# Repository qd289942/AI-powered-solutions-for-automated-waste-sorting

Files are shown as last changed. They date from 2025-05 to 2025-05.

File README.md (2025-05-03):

# 63184-fapra-ki-thema-1

Das Ziel des Projektes ist es, eine prototypische Fördereinrichtung zu erstellen,
welche vereinzelte Müllstücke transportiert. Die Müllstücke sollen
durch eine senkrecht über dem Förderband befestigte Kamera in Echtzeit
aufgenommen und durch einen KI-Basierten Bildverarbeitungsalgorithmus
ausgewertet werden. Die klassifizierten Müllstücke sollen anschließend durch
einen geeigneten Aktor vom Förderband entfernt und in die korrekte Müllgruppe
einsortiert werden.

Die Arbeit wurde im Rahmen des Moduls: “Fachpraktikum Softwareentwicklung
mit Methoden der Künstlichen Intelligenz” unter der Betreuung
von Dr. Otmane Azeroual erstellt. Die Aufgabenstellung mit dem Thema
„Automatisierte Mülltrennung und -entsorgung“ widmet sich, wie bereits
in vorherigen Kapiteln beschrieben, dem omnipräsenten Problem der Trennung
und Klassifizierung von kontinuierlich wachsenden Müllaufkommen.
Dieses Problem kann aus verschiedenen Blickwinkeln betrachtet und angegangen
werden, weswegen aus der Aufgabenstellung ein konkretes Vorgehen
und Projektziel abgeleitet wurde, welches in den nachfolgenden Abschnitten
beschrieben wird.

Das Projekt zielte auf die Automatisierung von Mülltrennung und -entsorgung ab und wurde erfolgreich als wissenschaftliche Arbeit veröffentlicht: "Intelligente Abfallwirtschaft: KI-gestützte Lösungen für automatisierte Mülltrennung und -entsorgung", Forschungsergebnisse zur Informatik, Band 75, Hamburg 2025 (ISBN 978-3-339-14368-6 Print / 978-3-339-14369-3 eBook). 

[Veröffentlichung](https://www.verlagdrkovac.de/978-3-339-14368-6.htm )

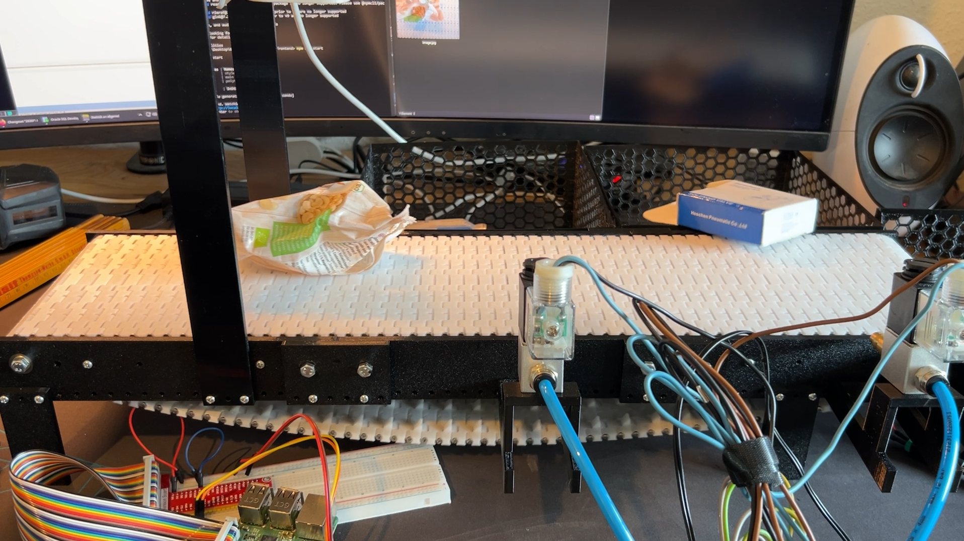
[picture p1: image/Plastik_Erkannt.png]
Förderband


## Starten der Anwendung
Zum starten der Anwendung folgen Sie bitte den Readme-Dokumenten des Frontends und des Backends

* [Backend](./backend/readme.md)
* [Frontend](./frontend/README.md)

## Standardbenutzer für Demozwecke
Zu Demozwecken stehen die beiden Nutzer admin und user zur Verfügung.
Die Passwörter entnehmen Sie bitte der env Datei des Backends.
[env](./backend/.env)
## Das vollständige Projekt-Demo
Das vollständige Projekt-Demo ist unter folgendem Link verfügbar:
[Video]https://drive.google.com/file/d/1swre4n_bvmbfQ7RDnxKk2m0LNGvAy1_f/view?usp=sharing

## Demo ohne Hardware
Ein detaillierte Demo-Video ohne Hardwareeinsatz wurde von unserem Teammitglied Herrn Teusch aufgenommen und ist unter folgendem Link einsehbar:
[Video](https://drive.google.com/file/d/1pbjZJ15CWwCAsQgvGXcbOX_87T2dLDAh/view)

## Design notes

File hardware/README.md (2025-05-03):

# Hardware
Für die Herstellung des Prototypen ...
benötigte Ausdrucke der Dateien:
 - 50x ChainFlat6Big.stl
 - 50x chainWithBottomTab6Big.stl
 - 2x FullFront6Big.stl
 - 2x Halterung Düse.stl
 - 2x Left.3mf
 - 2x Right.3mf
 - 2x middlerand6big.stl
 - 1x middlemiddle6big.stl
 - 4x Verbinder.stl
 - 2x wheel6big.stl

benötigte Gegenstände:
 - 4x QUARKZMAN 605ZZ 5x14x5mm Kugellager ([amazon.de](https://www.amazon.de/dp/B0BZP1FCC6?psc=1), [archive.org](https://web.archive.org/web/20240615102424/https://www.amazon.de/dp/B0BZP1FCC6?psc=1))
 - ca. 200x Linsenkopfschrauben DIN 7985 M2x3 bis M2x20 Kreuzschlitz ([ebay.de](https://www.ebay.de/itm/125243733851?var=426279012247), [archive.org](https://web.archive.org/web/20240615103334/https://www.ebay.de/itm/125243733851?var=426279012247))
 - 1x Druckluftkupplung Kupplungsstecker Außengewinde 1/4" ([amazon.de](https://www.amazon.de/dp/B003IJE1EG), [archive.org](https://web.archive.org/web/20240615102618/https://www.amazon.de/dp/B003IJE1EG))
 - 2x Elektrisches pneumatisches Magnetventil 2V025-08 12VDC PT1/4 2/2-Wege normalerweise geschlossen ([amazon.de](https://www.amazon.de/dp/B072ZZK9SD?psc=1), [archive.org](https://web.archive.org/web/20240615102828/https://www.amazon.de/dp/B072ZZK9SD?psc=1))
 - 1x Pneumatik Polyurethan PUN Schlauch 5 meter Außen 6mm x Innen 4mm ([amazon.de](https://www.amazon.de/dp/B071FM2H6R), [archive.org](https://web.archive.org/web/20240615103604/https://www.amazon.de/dp/B071FM2H6R))
 - 1x Kupplungsstecker mit Schlauchanschluss 6x4mm (mit Überwurfmutter) ([amazon.de](https://www.amazon.de/dp/B08KYQ4GB8), [archive.org](https://web.archive.org/web/20240615103808/https://www.amazon.de/dp/B08KYQ4GB8))
 - 1x Y-Stecker aus VooGenzek 20 Stück 6mm Air Push Schnellbefestigungen ([amazon.de](https://www.amazon.de/dp/B09NDNCQ89), [archive.org](https://web.archive.org/web/20240615104152/https://www.amazon.de/dp/B09NDNCQ89))
 - 1x 3 A 72W Verstellbarer Netzadapter, AC DC 3-24V Adapter Schaltnetzteil mit LED Spannungsanzeige ([amazon.de](https://www.amazon.de/dp/B09LCMMGJV), [archive.org](https://web.archive.org/web/20240615105202/https://www.amazon.de/dp/B09LCMMGJV))
 - 1x DC 12 V Getriebemotor, 25GA-370 25 Mm Durchmesser 12 V 30 U/min ([amazon.de](https://www.amazon.de/dp/B07HP6Z6CP), [archive.org](https://web.archive.org/web/20240615105715/https://www.amazon.de/dp/B07HP6Z6CP))

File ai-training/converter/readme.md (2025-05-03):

# Requirements

* Docker

# YOLOv8 to ONNX:

* Dockerfile: Dockerfile.yolov8_to_onnx
* Script: export_to_onnx.py

Build and Run:

```bash
docker build -t yolov8_to_onnx -f Dockerfile.yolov8_to_onnx .
docker run --rm -v $(pwd):/app yolov8_to_onnx #bash
```
```PowerShell
docker build -t yolov8_to_onnx -f Dockerfile.yolov8_to_onnx .
docker run --rm -v ${PWD}:/app yolov8_to_onnx #powershell
```

# YoloV8 to TensorFlow.js:
Legen Sie das exportierte YOLOv8 Model in den gleichen Ordner, wie
das Dockerfile.yolov8_to_tfjs.

Passen Sie im Dockerfile innerhalb des Bereiches ENTRYPOINT den Namen des Models an.
Dieser ist derzeit auf "detection.pt" eingestellt.

Achtung das erzeugte Image besitzt eine größe von ca. 13GB!

* Dockerfile: Dockerfile.yolov8_to_tfjs

Build and Run:
```bash
docker build -t yolov8_to_tfjs -f Dockerfile.yolov8_to_tfjs .
docker run --rm -v $(pwd):/app yolov8_to_tfjs #bash
```

```PowerShell
docker build -t yolov8_to_tfjs -f Dockerfile.yolov8_to_tfjs .
docker run --rm -v ${PWD}:/app yolov8_to_tfjs #PowerShell
```

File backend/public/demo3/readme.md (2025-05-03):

# Socket.IO Demo
Dies ist nur eine Demo, um die Arbeitsweise von Socket.IO zu veranschaulichen und eine Integration bestehnde Projekt zu demonstrieren.

Um die Demo zu testen muss das Projekt geklont werden, und die npm module installiert werden, siehe dazu readme für das Backend [klick](../../readme.md)

Anschließend muss der server gestartet werden `npm start`
Dann ruft man über einen Webbrowser die beiden folgenden links auf (der Port muss ggf. geändert werden, falls nicht der default Port verwendet wurde.)
* [https://localhost:3000/demo1](https://localhost:3000/demo1)
* [https://localhost:3000/demo3](https://localhost:3000/demo3)

Wenn man nun in Demo 1 ein Bild hochlädt und dort Müll erkannt wird, erhält Demo 3 ein Signal und Schaltet seinen Aktor an. Dieser wird dann automatisch nach 3 Sekunden wieder ausgeschaltet, um den Luftstoß zu signalisieren.
Derzeit ist noch zu definieren, wie die Das Objekt des Servers aussehen soll. Hier sollten wir uns auf einen Interface einigen. 
Anschließend stellt sich noch die Frage, ob für alle Aktoren Befehle empfangen möchte, oder ob das Backend für einen Aktor eine
eigene Route erstellen soll, auf die man sich dann verbindet. 

# Socket.IO Python Demo

Für die Python Version muss natürlich Pyhton installiert sein.
Anschließend muss noch das Socket.IO Modul installiert werden `pip install "python-socketio[client]"`.
Bevor nun der Python client gestartet wird sollte das Backend gestartet werden, dazu wie in der [Readme des backends verfahren](../../readme.md)
anschließend kann der test mittels `py.exe .\socketio-test.py` aus dem order backend\public\demo3 getartet werden.

Die Konsole sollte offen bleiben.
Öffnet man nun [https://localhost:3000/demo3](https://localhost:3000/demo3)

Weitere Referenzen unter: 
https://python-socketio.readthedocs.io/en/latest/client.html#installation

# Registrierung eines Aktores auf eine Socket.IO Route
Damit ein Aktor über eine erkannte Müllklasse informiert werden kann, muss sich dieser auf seine eigene Socket verbinden.
Jeder Aktor erhält somit seine eigene Socket.io Route, über die informiert wird. 
Die Route ist wie folgt aufgebaut: 

```trash_detected/${actuatorId}```

Ein Beispiel für den Aktor mit der ID 1 wäre

trash_detected/1

Ein Beispiel für den Aktor mit der ID 15 wäre
trash_detected/15

in form von Python Code könnte dies so aussehen: 
```python
sio.on('trash_detected/1', trigger_actuator)
```

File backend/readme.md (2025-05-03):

# Installation des Backends

> Voraussetzungen für die Installation:
> * [Node.js](https://nodejs.org/en/download)
> * [Docker](https://www.docker.com/products/docker-desktop/)

1. Klonen Sie das Repository mittels git clone
```bash
git clone https://code.dbis-pro1.fernuni-hagen.de/fpniteus/63184-fapra-ki-thema-1.git
```

2. Navigieren Sie in das Verzeichnis backend 
```bash
cd backend
```

3. Installieren Sie die Node-Modules mittels
```bash
npm install
```

4. Kopieren einer benötigten dll in das ein Tensorflow unterverzeichnis. Weitere Informationen können diesbezüglich [Fehler-nach-Installation](#Fehler-nach-Installation)
```bash
cp .\node_modules\@tensorflow\tfjs-node\deps\lib\tensorflow.dll .\node_modules\@tensorflow\tfjs-node\lib\napi-v8\
cp .\node_modules\@tensorflow\tfjs-node\deps\lib\tensorflow.dll .\node_modules\@tensorflow\tfjs-node-gpu\lib\napi-v8\
```

Die folgenden Schritte sind Optional und werden nur benötigt, wenn die KIs auf der GPU Laufen sollen.

Voraussetzungen: 
* NVIDIA Grafikkarte
The following NVIDIA® software are only required for GPU support.

* Windows Native Requires Microsoft Visual C++ Redistributable for Visual Studio 2015, 2017 and 2019
NVIDIA® GPU drivers
* >= 525.60.13 for Linux
* >= 528.33 for WSL on Windows (Falls keine native Ausführung auf Windows gewünscht ist.)
* CUDA® Toolkit 12.3.
* cuDNN SDK 8.9.7.
* (Optional) TensorRT to improve latency and throughput for inference.

[Eine Installationsanleitung für CUDA kann hier entnommen werden](https://www.tensorflow.org/install/pip#windows-native_1)

# Starten des Backends
Nach der [Installation](#Installation-des-Backends) sollte zuerst die Datenbank gestartet werden. Navigieren Sie hierzu in den Unterordner backend und führen `docker-compose up` aus. Es sollte nun ein docker-container mit der Datenbank gestartet werden. Anschlißeend kann mittels `npm start` das Node.js backend gestartet werden.

# Ausführen von Testfällen
Die Testfälle können mittels des Befehls `npm test` im Untterordner backend ausgeführt werden.

# Fehler nach Installation
Dieser Fehler trat nur unter Windows (x86_64) auf. Die Installation unter macOS M1 ARM verlief fehlerfrei.

```
node:internal/modules/cjs/loader:1189
return process.dlopen(module, path.toNamespacedPath(filename));
```

Nach der Installation wurde ein Fehler angezeigt, dass ein Modul nicht geladen werden konnte.

hierzu muss eine dll in den Entsprechenden Ordner kopiert werden.

```bash
cp .\node_modules\@tensorflow\tfjs-node\deps\lib\tensorflow.dll .\node_modules\@tensorflow\tfjs-node\lib\napi-v8\
```

[Quelle](https://github.com/tensorflow/tfjs/issues/8176)

# Docker einrichten & DB aufsetzen

`docker compose up -d`

DB Index über Kibana http://127.0.0.1:5601/app/dev_tools#/console anlegen:

```http request
PUT detected_garbage
{
  "mappings": {
    "properties": {
      "bounding_box": {
        "properties": {
          "height": {
            "type": "float"
          },
          "width": {
            "type": "float"
          },
          "x": {
            "type": "float"
          },
          "y": {
            "type": "float"
          }
        }
      },
      "detection_certainty": {
        "type": "float"
      },
      "detection_class": {
        "type": "keyword"
      },
      "detection_timestamp": {
        "type": "date"
      },
      "img_path": {
        "type": "keyword"
      },
      "tracking_id": {
        "type": "keyword"
      },
      "x_detection_threshold" : {
        "type": "float"
      },
      "ai_id" : {
        "type": "long"
      },
      "operation_section_id" : {
        "type": "long"
      }
    }
  }
}
```

Ist der Index bereits vorhanden, kann er mithilfe des folgendes Requests gelöscht werden,
dabei gehen alle bereits gespeicherten Daten verloren:

```http request
DELETE detected_garbage
```

Möchte man nur die gespeicherten Daten entfernen ohne den Index selbst zu entfernen kann folgender Request genutzt werden:

```
POST detected_garbage/_delete_by_query
{
    "query": {
        "match_all": {}
    }
}
```

## Rebuild der Container durchführen
Falls Änderungen an den Cotnainers durchgeführt werden kann es notwendig sein einen rebuild durchzuführen.
Dies ist beispielsweise der Fall, wenn das KI-Modell ausgetauscht wurde, jedoch noch den gleichen Namen besitzt.
Führen Sie in diesem Fall folgenden Befehl aus: 

`npm run rebuild-container`

# Eindung weiterer KI-Modelle

Zur Einbinden weiterer KI-Modelle müssen in das Tensorflow.JS-Format konvertiert werden.
Hierfür kann der Konverter unter ai-training/converter genutzt werden. Lesen Sie die dort vonrhandene [readme.md](../ai-training/converter/readme.md)
für die Konvertierung.

Anschließend erhalten Sie ein verzeichnis mit dem Namen des exportierten Modells. Dieses sollte einer gewissen Anzahl an shard-Dateinen bestehen, eine metadata.yml sowie eine model.json enthalten.

Kopieren Sie dieses Verzeichnis nach `backend/src/models/`
Anschließend kann eine neue Instanz der Klasse YoloV8 erzeugt werden.
Übergeben Sie dem Konstruktor den Namen des Ordners (modelName).
Zuletzt muss das erzeugte Objekt, dem ObjectDetectionRouter mit den anderen KIs übergeben werden.

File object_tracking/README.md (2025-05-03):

# Prototyp Objektverfolgung (object-tracking)

In diesem Teilprojekt sollen Lösungsansätze für das Problem object-tracking (Wiederkennung von Objekten über mehrere Frames hinweg) evaluiert werden.

Da dieses Teilprojekt einen reinen Prototyp-Charakter hat wurden die Skripte unter zuhilfenahme von ChatGPT 4o von OpenAI in Grundzügen erstellt und händisch
in seiner Funktionsweise komplettiert.

Beim Ordner 

## Vorbereitung der Umgebung

Das Projekt muss in `PyCharm Professional` geöffnet werden, dieses sollte nach dem öffnen automatisch, eine virtuelle Umgebung `venv` erstellen,

Falls dies nicht der Fall ist muss diese manuell erstellt werden, Python `3.12.3` ist Voraussetzung.

Für die Evaluation wurde yolov5 (Ein vortrainiertes Model mit niedriger Inferenzzeit) verwendet, dies muss mittels folgendem Befehl ins Hauptverzeichnis gecloned werden:

`git clone https://github.com/ultralytics/yolov5`

Dann müssen Folgende Abhängigkeiten müssen mittels folgender Befehle unter Verwendung von `pip` installiert werden

```
pip install -r yolov5/requirements.txt
pip install opencv-python opencv-python-headless ultralytics deep_sort_realtime
pip install numpy opencv-python
pip install torch torchvision
```

Nach diesem Schritt sind alle Abhängigkeiten installiert.

## Vorbereitung und Ausführung der Evaluation mittels Projekt-Skripten

Um das Projekt zu benutzen müssen zunächst 3 Videos unter `./video` abgelegt werden.

Es gibt folgende Python-Skripte mit ihren jeweiligen Teilaufgaben welche in der folgenden Reihenfolge ausgeführt werden müssen:

* `split_to_frames.py`
  * zerschneidet die in `video` abgelegten Videos in einzelne Frames, welche unter `./frames` abgelegt werden
* `detect_objects.py`
  * Nutzt ein KI-Model um object-detection auf die in `./frames` gespeicherten Bilder auszuführen und schreibt die Bilder inklusive Klassifizierung
und bounding-box in `./detection`. Hierbei handelt es sich lediglich um einen Schritt der bessere Nachvollziehbarkeit der Effektivität des object-trackings gewährleisten soll.
* `track_objects.py`
  * Nutzt ein KI-Model (es muss dasselbe wie im vorherigen Schritt sein) um object-detection und anschließend object-tracking durchzuführen.
  * Das Ergebnis (Bilder mit BBoxes und IDs) wird unter `./tracking` abgelegt.
* `create_videos.py`
  * Nutzt die unter `./tracking` abgelegten Bilder und erstellt daraus Videos zur besseren Veranschaulichung 

Am Ende stehen die im letzten Schritt erzeugten Videos unter `end_results` zur Verfügung.

In diesem Teilprojekt geht es aktuell um die qualitative Evaluation von object-tracking Ansätzen, daher werden aktuell keine Metriken zur Präzision
ermittelt.

## Quick-Demo

Unter dem Link https://drive.google.com/drive/folders/12NR1LaL0RtI5wm9HxKmUK7CR1UAvKl8M?usp=drive_link#
gibt es alle Dateien welche während einem Probelauf entstanden sind.

## Aktueller Stand

Zunächst wurde die Evaluation mittels einem nicht nachtrainierten `yolov5` durchgeführt.

Dabei zeigte sich, dass der bisherige Ansatz `DeepSort` qualitativ erfolgversprechend aussieht.

Der nächste Schritt besteht nun das object-tracking mittels eines angepassten models zu trainieren.

Die dafür nötigen Anpassungen sind zum jetzigen Zeitpunkt noch nicht final, aktuelle Versionen der modifizierten Skripte werden
unter `wip_aligned` abgelegt.

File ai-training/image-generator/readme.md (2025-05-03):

# Kurzbeschreibung

Der Imagegenerator erzeugt jede Sekunde einen Screenshot, von dem Bild, welches die Kamera gerade aufnimmt und speichert es im Format
640x640 px im Backend im unterordner ./images.

# Installation
1. Navigieren Sie in den Unterordner image-generator
2. führen Sie ein `npm i` aus, um die Node-Moduels zu installieren
3. Starten des Image-Generators mittels `npm start`
4. Der Image-Generator ist nun unter https://localhost:3001/ erreichbar

# Wechseln der Kamera
Der Image-Generator selbst besitzt keine eigene möglichkeit die Ausgewählte Kamera zu ädern. Hierfür muss auf die eingebauten funktionen des Browsers zurückgegriffen werden.

1. Google Chrome starten
2. https://localhost:3001 aufrufen
3. Richtige Kamera auswäheln
   1. Auf Kamera Symbol in der URL Leiste klicken

    

   2. Manage
   
   

   3. Auf das Kamera Dropdown klicken
   
   

   4. Richtige Kamera auswählen
   
   
   
   5. Seite neu laden

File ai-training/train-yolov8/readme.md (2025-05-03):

# Training von YOLOv8 Detektions/Klassifikations-Modell

In diesem Test wurde YOLOv8 Verwendet und es mit einem Dataset für Mülltrennung trainiert. Zuerst wird ein Klassifikationsmodell mit einem Datensatz von Kaggle trainiert und anschließend ein Detektionsmodell mit Bildern sowohl von Kaggle als auch von einem Förderband trainiert.

Hierbei handelt es sich um einen Versuch, eines Basismodells (yolov8s für Detektion bzw. yolov8s-cls für Klassifikation) auf ein neues Einsatzgebiet zu trainieren.

Das Tutorial hierfür findet sich unten:

1. Tutorial für Klassifikation [hier](https://docs.ultralytics.com/tasks/classify/)
2. Tutorial für Detektion [hier](https://docs.ultralytics.com/tasks/detect/)

## Datenquelle der Mülltrennung

1. Datensatz aus Kaggle [hier](https://www.kaggle.com/datasets/asdasdasasdas/garbage-classification)
2. Frame-für-Frame-Zerlegung eines Videos eines Förderbands mit verschiedenen Müll

## Voraussetzung

Bevor Sie beginnen, stellen Sie sicher, dass Sie die folgenden Werkzeuge und Bibliotheken installiert haben:
- Python (3.8 oder höher)
- [Anaconda](https://www.anaconda.com/)
- NVIDIA CUDA Toolkit (für GPU-Beschleunigung) 12.4 oder höher

## Setup der Umgebung

Virtuelle Umgebung erstellen und aktivieren

    conda create -n yolov8_env
    conda activate yolov8_env

YOLOv8 und Abhängigkeiten installieren:

    pip install ultralytics

# Install all packages together using conda
conda install -c pytorch -c nvidia -c conda-forge pytorch torchvision pytorch-cuda=11.8 ultralytics

Setting Up ClearML zur Visualisierung:
    
    pip install clearml 

Hier sind die Schritte zur Generierung und Hinzufügung des API-Schlüssels für ClearML:

- Erstellen Sie ein ClearML-Konto.
- Gehen Sie zu Einstellungen => Arbeitsbereich und klicken Sie auf "Neue Anmeldeinformationen erstellen".
- Kopieren Sie die Informationen unter dem LOCAL PYTHON Tab.
- Öffnen Sie das Terminal und aktivieren Sie die Umgebung, in der ClearML installiert ist.
- Geben Sie clearml-init ein und führen Sie es aus.
- Sie werden aufgefordert, die zuvor kopierten Informationen einzufügen.
- Ihre ClearML-Anmeldeinformationen sind nun im System hinterlegt.

CUDA installieren:

```python
nvidia-smi # check the GPU drive

conda install pytorch torchvision torchaudio pytorch-cuda=11.8 -c pytorch -c nvidia

or pip install torchvision==0.17.0+cu118 torchaudio==2.2.0+cu118 -f https://download.pytorch.org/whl/torch_stable.html

```

## Datensatz

### Struktur

Datensatzstruktur für YOLO Klassifikation [hier](https://docs.ultralytics.com/datasets/classify/)

Datensatzstruktur für YOLO Detektion [hier](https://docs.ultralytics.com/datasets/detect/)

### Anotation

Mithilfe eines Labeling-Tools (Label Studio) wurden die Bilder (mehr als 2000) annotiert.
```python
# Requires Python >=3.8
pip install label-studio

# Start the server at http://localhost:8080
label-studio
```

### Konfiguration

Das Ultralytics YOLO-Format ist ein Datensatz-Konfigurationsformat, das es ermöglicht, das Wurzelverzeichnis des Datensatzes, die relativen Pfade zu den Verzeichnissen für Trainings-/Validierungs-/Testbilder oder *.txt-Dateien mit Bildpfaden sowie ein Wörterbuch von Klassennamen zu definieren. Hier ist ein Beispiel data.yaml:

```yaml
# Train/val/test sets as 1) dir: path/to/imgs, 2) file: path/to/imgs.txt, or 3) list: [path/to/imgs1, path/to/imgs2, ..]
path: ../datasets/Garbage_classification  # dataset root dir
train: images/train  # train images (relative to 'path')
val: images/val  # val images (relative to 'path')
test:  images/test

# Classes (6 classes)
names:
  0: cardboard
  1: glass
  2: metal
  3: paper
  4: plastic
  5: trash
```
## Training

Trainiere YOLOv8n auf dem Mülltrennung-Datensatz für 100 Epochen bei einer Bildgröße von 640. Eine vollständige Liste der verfügbaren Argumente findest du auf der [Konfigurationsseite](https://docs.ultralytics.com/usage/cfg/). Hier ist auch ein Beispiel Training mit yolov8m.pt für Detektion:

```python
import torch
from ultralytics import YOLO

def main():
    model = YOLO('yolov8m.pt')
    results = model.train(data="data.yaml", epochs=100, imgsz=640)

if __name__ == "__main__":
    import multiprocessing
    multiprocessing.freeze_support() 
    main()
```

## Vorhersage

Nutzen Sie ein trainiertes YOLOv8n Modell, um Vorhersagen auf Bildern durchzuführen

```python
from ultralytics import YOLO

# Laden des Modells
model = YOLO("path/to/best.pt") 

# Vorhersage mit dem Modell
results = model("https://ultralytics.com/images/bus.jpg")
```

Mit einem trainierten Modell und der OpenCV-Bibliothek Echtzeit-Videoerkennung mit Bounding-Box durchführen:

```python
from ultralytics import YOLO
import cv2

model = YOLO(r'')

cap = cv2.VideoCapture(r'')

while cap.isOpened():
    ret, frame = cap.read()
    if not ret:
        break

    results = model(frame)

    for result in results:
        boxes = result.boxes
        for box in boxes:

            x1, y1, x2, y2 = box.xyxy[0].cpu().numpy().astype(int)
            label = result.names[box.cls[0].item()] 
            confidence = box.conf[0].item()

            cv2.rectangle(frame, (x1, y1), (x2, y2), (0, 255, 0), 2)
            cv2.putText(frame, f'{label}: {confidence:.2f}', (x1, y1 - 10), cv2.FONT_HERSHEY_SIMPLEX, 0.5, (0, 255, 0), 2)

    cv2.imshow('YOLOv8 Video Detection', frame)

    if cv2.waitKey(1) & 0xFF == ord('q'):
        break

cap.release()
cv2.destroyAllWindows()
```

## Export

Exportieren Sie ein YOLOv8n-Modell in ein anderes Format wie ONNX oder CoreML. Informationen für Format finden Sie [hier](https://docs.ultralytics.com/tasks/detect/#predict)

```python
from ultralytics import YOLO

model = YOLO("path/to/best.pt")  

model.export(format="onnx")
```

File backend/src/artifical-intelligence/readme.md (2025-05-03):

# Aufbau des Interfaces

Das Interface IArtificialIntelligence besteht aus den zwei öffentlichen Methoden getDetectionCapabilities und detectImage.
Die Methode getDetectionCapabilieties dient dazu abzufragen, welche Trashlabels die KI erzeugen kann. Dies kann sinnvoll sein,
wenn mehrere KIs vorhanden sind, die auf die auf verschiedene Arten von Müll spezialisiert wurden. Beispielsweise könnte man
eine KI dazu verwenden, um explizit Plastik zu erkennen. Eine andere Hingegen für Glas und eine weitere für Metall.
Über die detectionCapabilites kann also ausgewertet werden, auf welche Arten von Müll die KI reagiert.
In dem Fall unseres selbst trainierten Yolo-Modells sind diese: 

   * cardboard
   * glass
   * metal
   * paper
   * plastic
   * trash

Die zweite Methode detectImage dient der eigentlichen Auswertung des Bildes durch die KI.

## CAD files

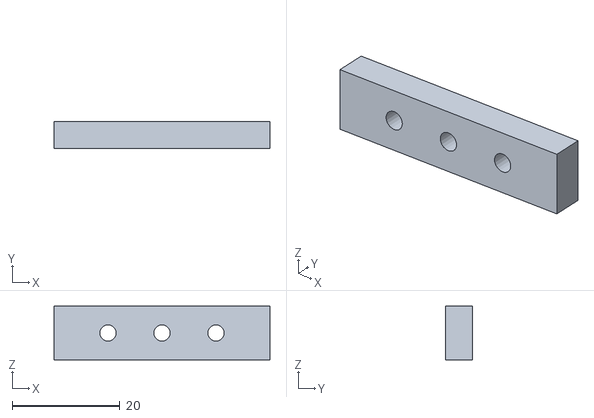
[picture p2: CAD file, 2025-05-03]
hardware/3D Dateien/Webcam Halter Platte.stl
40.0 x 5.00 x 10.0

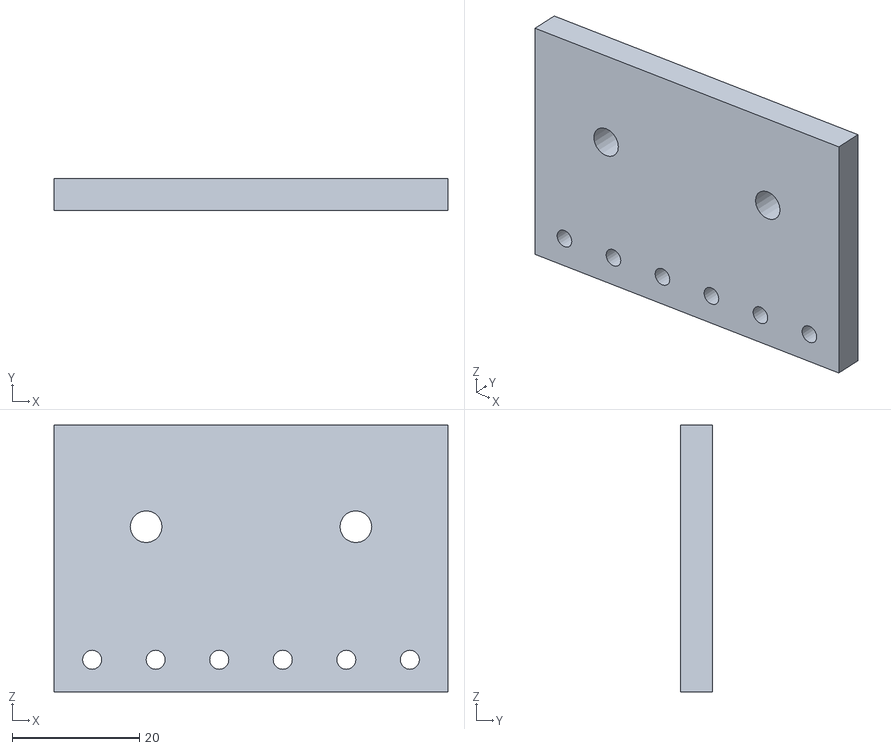
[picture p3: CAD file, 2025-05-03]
hardware/3D Dateien/Verbinder.stl
62.0 x 5.00 x 42.0

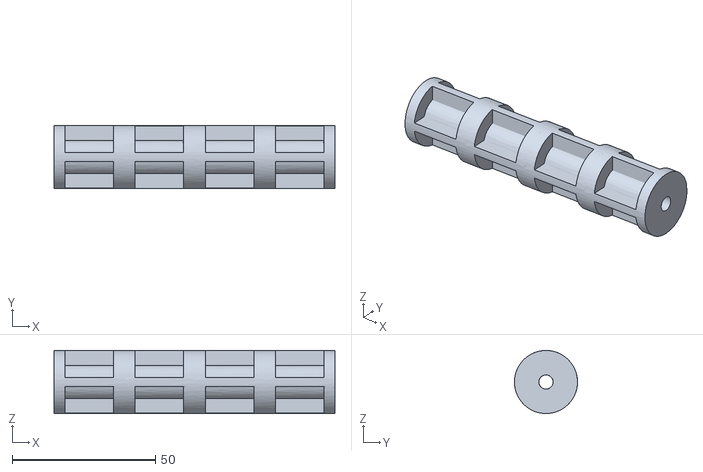
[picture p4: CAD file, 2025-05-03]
hardware/3D Dateien/wheel4big.stl
98.0 x 22.0 x 22.0

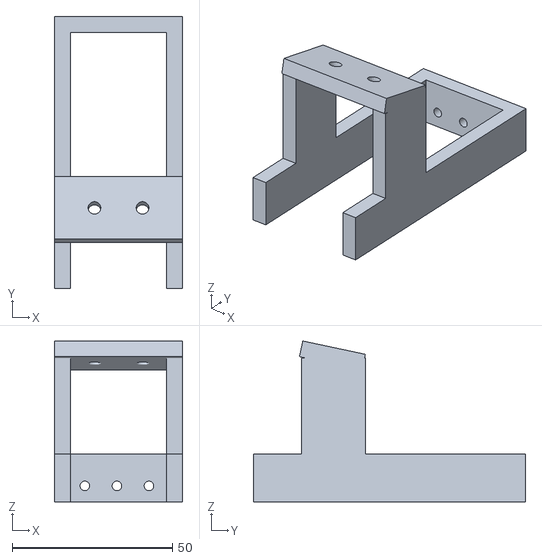
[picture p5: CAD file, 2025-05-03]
hardware/3D Dateien/Halterung Düse schräg.stl
40.0 x 85.0 x 50.3

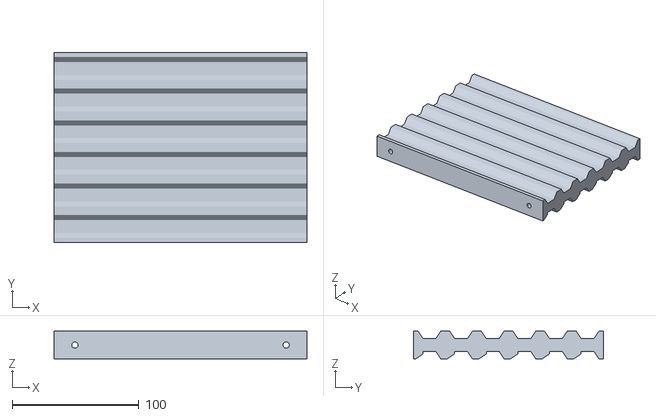
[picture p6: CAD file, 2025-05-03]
hardware/3D Dateien/middlemiddle6big.stl
200.0 x 150.0 x 22.0

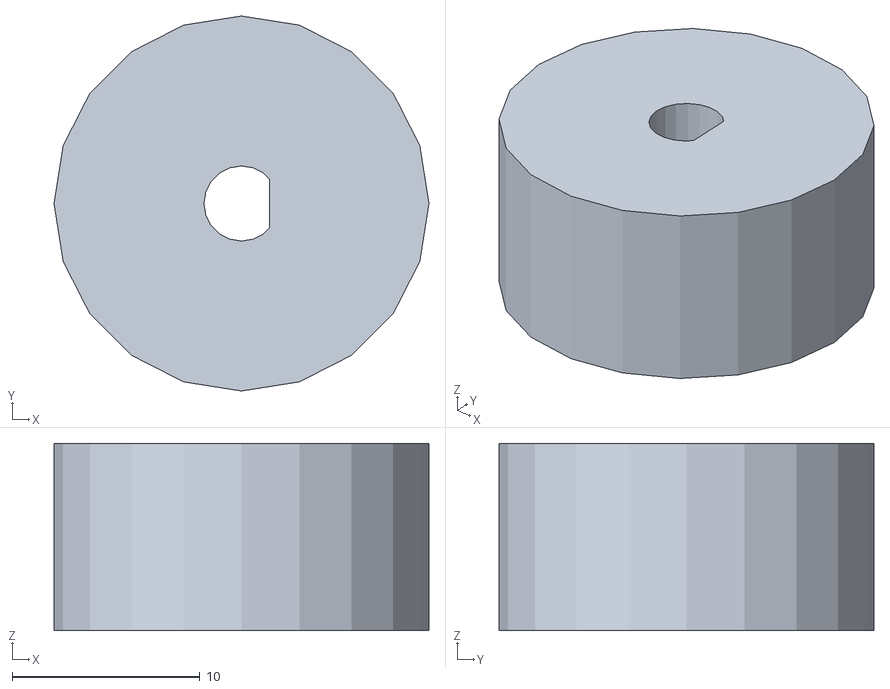
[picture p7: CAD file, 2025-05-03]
hardware/3D Dateien/Adapter Sechskant Motor.stl
20.0 x 20.0 x 10.0

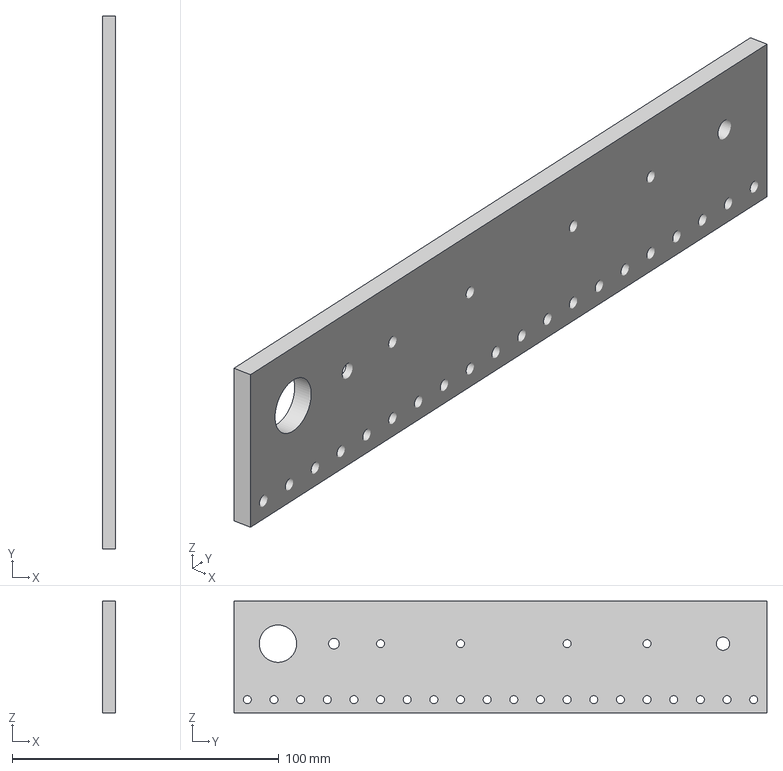
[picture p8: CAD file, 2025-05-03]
hardware/3D Dateien/Left.3mf
5.00 x 200.0 x 42.0 mm

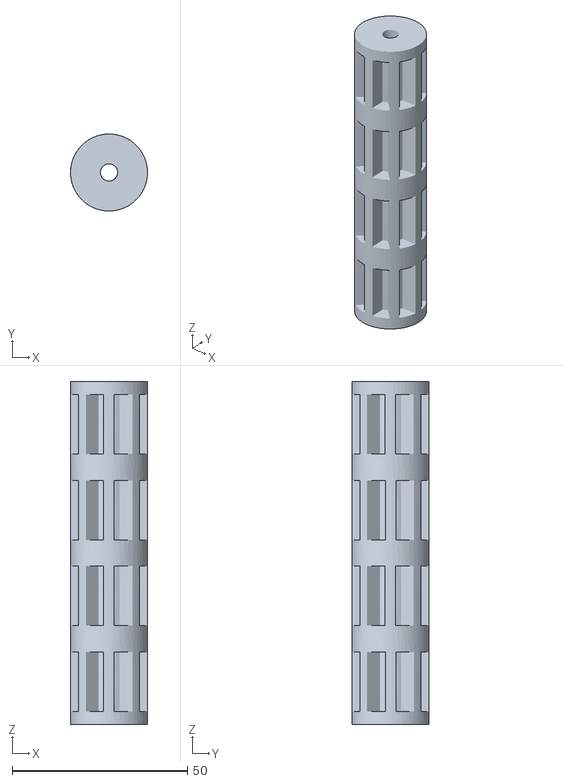
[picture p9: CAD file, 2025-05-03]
hardware/3D Dateien/wheeldouble4big.stl
22.0 x 22.0 x 98.0

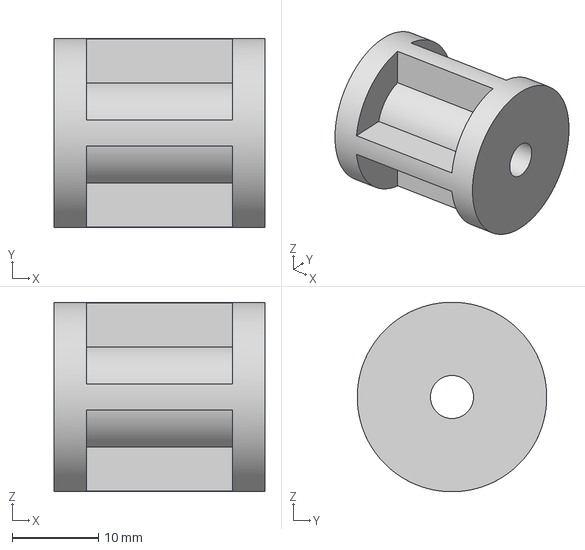
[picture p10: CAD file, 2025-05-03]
hardware/3D Dateien/Wheel.3mf
24.5 x 22.0 x 22.0 mm

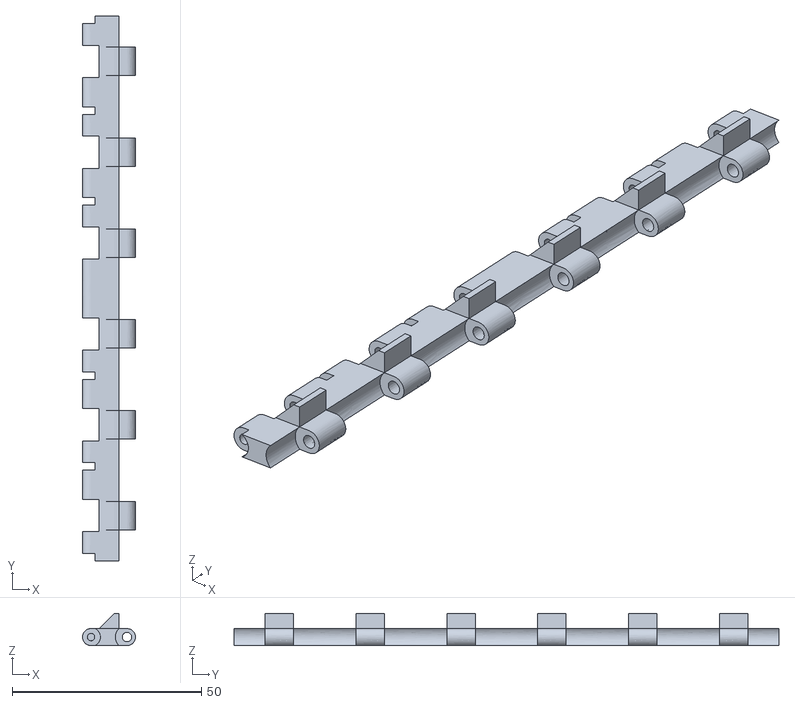
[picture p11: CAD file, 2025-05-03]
hardware/3D Dateien/chainWithBottomTab6Big.stl
14.0 x 144.0 x 8.50

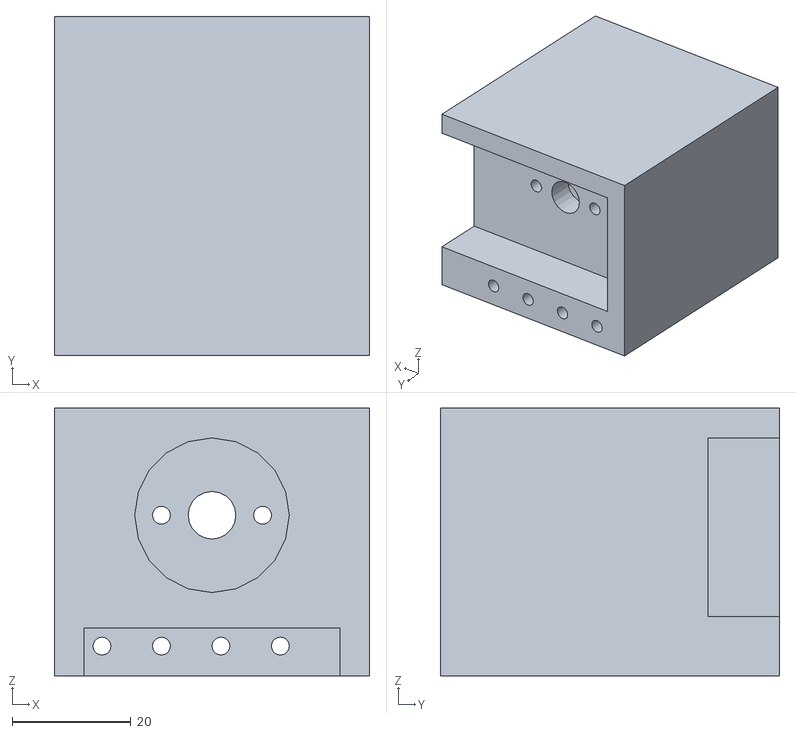
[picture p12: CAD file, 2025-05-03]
hardware/3D Dateien/Motorenhalter.stl
53.0 x 57.0 x 45.0

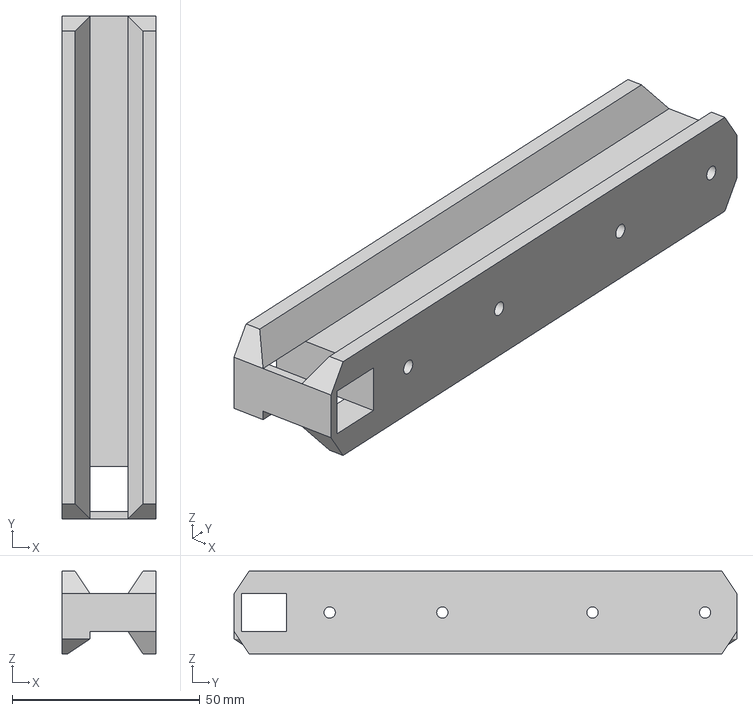
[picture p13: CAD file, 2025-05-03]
hardware/3D Dateien/Middle.3mf
25.0 x 134.0 x 22.0 mm

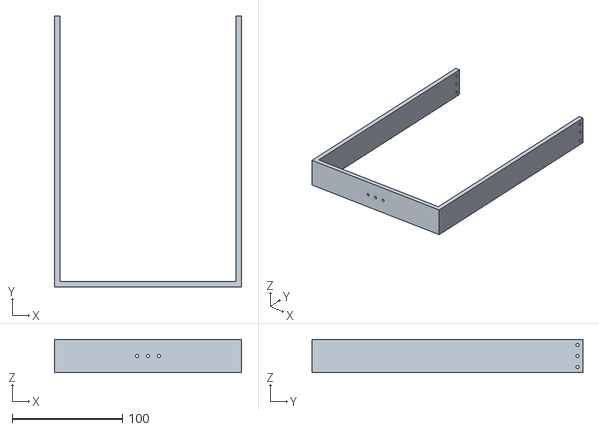
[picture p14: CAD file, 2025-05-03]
hardware/3D Dateien/Webcam Halter.stl
170.0 x 246.0 x 30.0

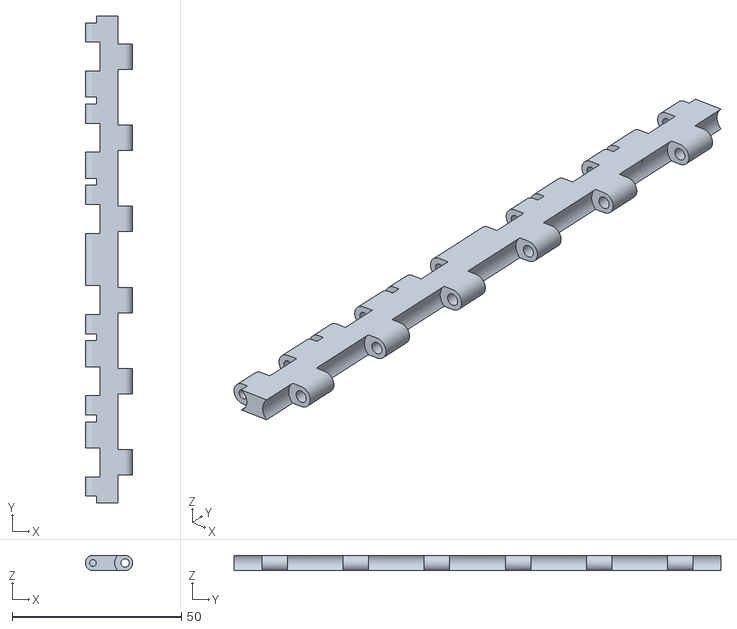
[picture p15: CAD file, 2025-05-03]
hardware/3D Dateien/ChainFlat6Big.stl
14.0 x 144.0 x 4.50

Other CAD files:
hardware/3D Dateien/Aussen Mitte.stl
hardware/3D Dateien/Front6big.stl
hardware/3D Dateien/middle4big.stl
hardware/3D Dateien/Right.3mf
hardware/3D Dateien/Fuß.stl
hardware/3D Dateien/wheel6big.stl

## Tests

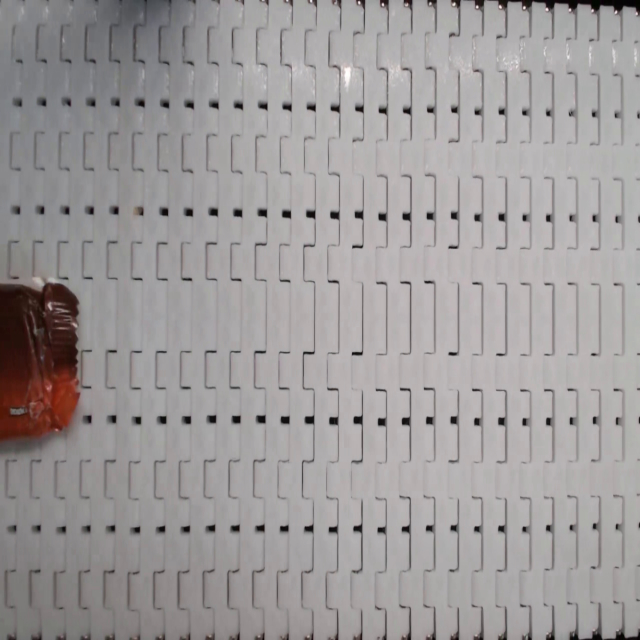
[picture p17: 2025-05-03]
backend/tests/http/tracking/img/640x640/frame_0148.jpg

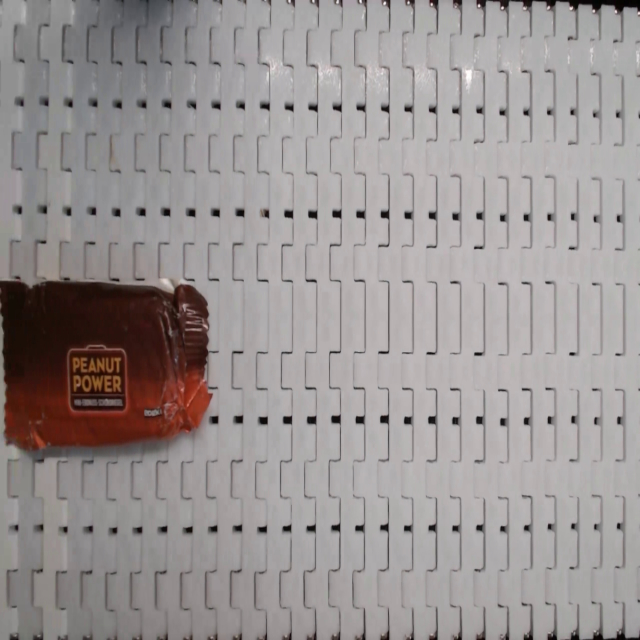
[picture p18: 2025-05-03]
backend/tests/http/tracking/img/640x640/frame_0222.jpg

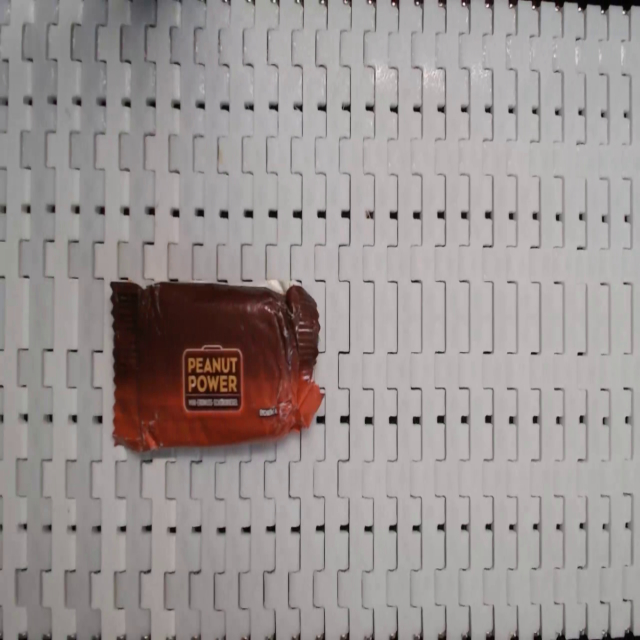
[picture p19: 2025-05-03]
backend/tests/http/tracking/img/640x640/frame_0289.jpg

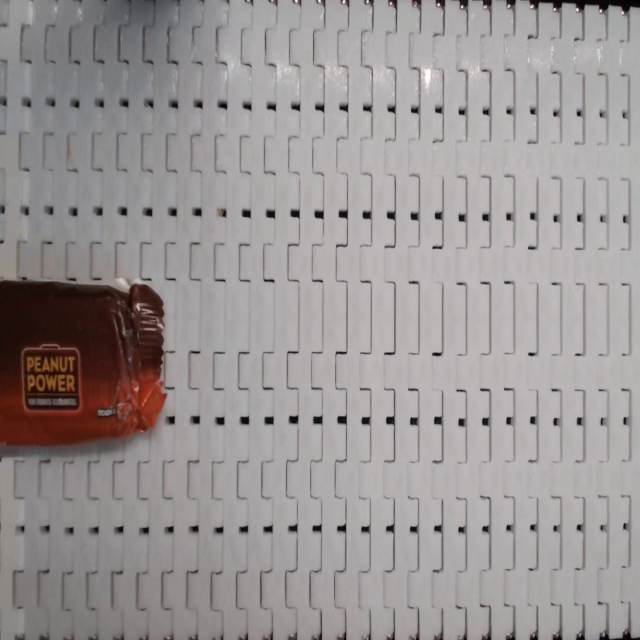
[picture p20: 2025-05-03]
backend/tests/http/tracking/img/640x640/frame_0198.jpg

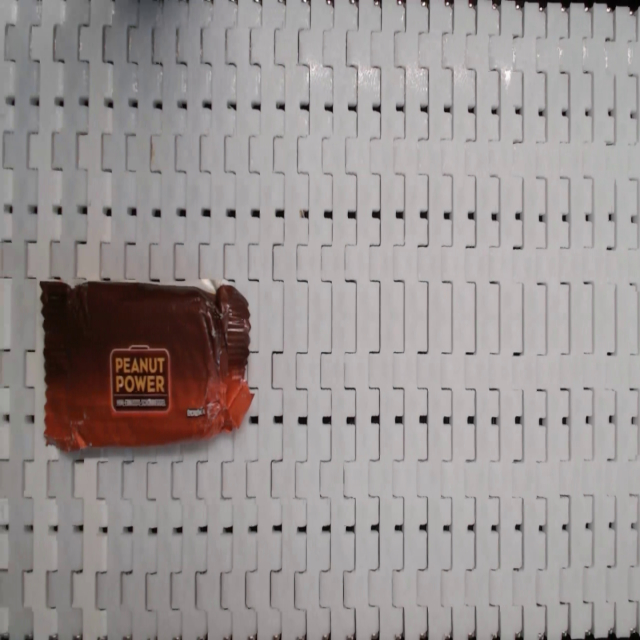
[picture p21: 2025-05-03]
backend/tests/http/tracking/img/640x640/frame_0248.jpg

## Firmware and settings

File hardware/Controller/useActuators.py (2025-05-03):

import socketio
import RPi.GPIO as GPIO
import time
import argparse
import logging

actuator1Pin = 17
actuator2Pin = 27

sio = socketio.Client(ssl_verify=False, )

def setup():
    logging.info(f"Setup")
    GPIO.setmode(GPIO.BCM)
    GPIO.setup(actuator1Pin, GPIO.OUT, initial=GPIO.HIGH)
    GPIO.setup(actuator2Pin, GPIO.OUT, initial=GPIO.HIGH)

@sio.event
def connect():
    logging.info(f"Verbindung hergestellt")

@sio.event
def my_message(data):
    logging.info(f"Nachricht erhalten: ", data)

@sio.event
def disconnect():
    logging.info(f"Verbindung zum Server verloren")

def n1(data):
    logging.info(f"{data['predictionClass']} start")
    GPIO.output(actuator1Pin, GPIO.LOW)
    time.sleep(1.5)
    logging.info(f"{data['predictionClass']} end")
    GPIO.output(actuator1Pin, GPIO.HIGH)

def n2(data):
    logging.info(f"{data['predictionClass']} start")
    GPIO.output(actuator2Pin, GPIO.LOW)
    time.sleep(1.5)
    logging.info(f"{data['predictionClass']} end")
    GPIO.output(actuator2Pin, GPIO.HIGH)

def main(actuatorId1, actuatorId2):
    sio.connect('http://192.168.22.24:3000', )
    sio.on(f"trash_detected/{actuatorId1}", n1)
    sio.on(f"trash_detected/{actuatorId2}", n2)
    sio.wait()

def destroy():
    GPIO.output(actuator1Pin, GPIO.HIGH)
    GPIO.output(actuator2Pin, GPIO.HIGH)

    GPIO.cleanup()

if __name__ == '__main__':
    parser = argparse.ArgumentParser(description='Stellt Verbindung zwischen Actuators und Backend her und gibt Auslösesignal an Actuators.')
    parser.add_argument('--actuatorId1', type=str, default='1', help='Die Id des ersten Actuators.')
    parser.add_argument('--actuatorId2', type=str, default='2', help='Die Id des zweiten Actuators.')
    
    args = parser.parse_args()

    logging.basicConfig(
    format='[%(asctime)s] %(message)s',
    datefmt='%d.%m.%Y %H:%M:%S',
    level=logging.INFO)

    logging.info(args)

    setup()
    try:
        main(args.actuatorId1, args.actuatorId2)
    except KeyboardInterrupt:
        destroy()
